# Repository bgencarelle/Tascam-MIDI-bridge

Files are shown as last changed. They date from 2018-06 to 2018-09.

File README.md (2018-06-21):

---
name: Midi to Tascam Serial Control
Usage: Midistudios and devices that use the Tascam Accessory 2 port.
---
**Goals:**

The goal of this project is to create an open device that can replace the obsolete and all but impossible-to-find sync devices for various Tascam tape machines.

**The desired functions:**

MIDI transport control of all functions available over the serial port.

SMPTE Time Code Chase to external reference.

Speed/pitch control of transport.

**Current Status:**

Midi control over all of the stuff controlled by the serial port for these devices has already been finished. You may want to change the CC's to something more useful by you, as they were setup to be most useful with my MIDI controller.

There are two sketches-one solely for external control and one for external control plus SMPTE sync.

The timing sync is not finished as of June 2018, but the decoders both work well.

I do plan on adding DAC based pitch control, whether or not I get the timing working.

I also plan on generalizing this to make for a control thing for non-serial enabled tape machines.

This is written for the Arduino UNO as it is cheap and easily sourced, but, virtually anything Arduino compatible will work.

Obviously USB midi and Bluetooth can be used, but are not currently implemented.

**Hardware roughly required**

Arduino compatible microcontroller.

Some sort of inverter/buffer to convert the UART data to reasonable voltages for RS-232.

Driver/inverter to get the LTC to digital levels.

Opto-isolator for standard MIDI.

**Hardware specifically used**

Arduino Uno with Midi Shield CD 4049 inverter for both converting LTC from audio to digital levels and two other pins for the UART inversion and voltage conversion.<p>
Various resistors and caps.
<p>USB FTDI UART thing for debugging.

You may want to use better hardware. I had no problems, but that doesn't mean anything!

**Notes on the Serial and MIDI format**

There is a pinout available in the documents as both a GIF and a PDF.

Basically just remember to connect your transmit to the device's receive.
Do not forget to both protect and invert the inputs to save your device from the higher and lower voltages that RS-232 uses.

The RS-232 format is 9600 baud, 8 bits, even parity, no handshaking.
This slightly odd format is why the standard SoftwareSerial library could not be used.

Each message is sent as a byte, or a pair of bytes followed by usual end of line characters.

Make sure to wait 100ms between messages. This won't be a problem usually.

**Attribution and licenses**

Use it, fork it, do whatever, but make sure to keep it freely available, give me a bit of credit and respect the licenses of the people who made these libraries.

https://creativecommons.org/licenses/by-sa/4.0/

The MIDI and LTC portions of this code are lifted from various Arduino.cc forums:
<http://arduino.cc>

SoftwareSerialParity comes from:
<https://github.com/ledongthuc/CustomSoftwareSerial>

This has been converted into an Arduino compatible library in the same directory as these sketches.

All related documents used for research can be found in this repository.

Thanks to Tascam for providing the documentation.

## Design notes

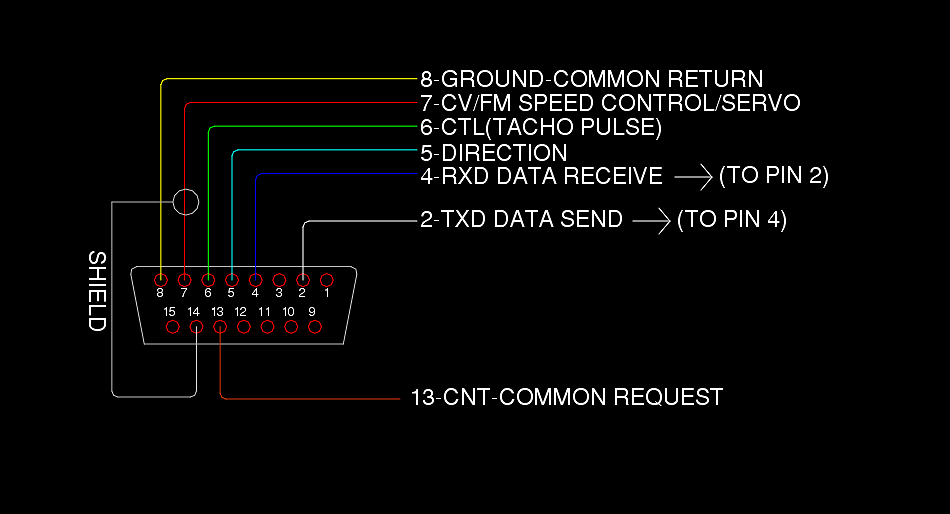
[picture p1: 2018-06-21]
diagrams/ACCESSORY2_pinout.gif

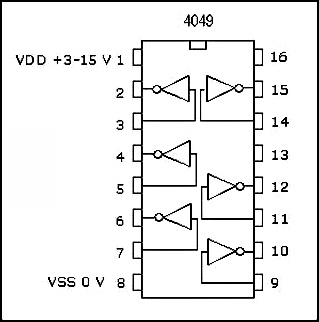
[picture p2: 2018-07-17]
diagrams/IC-CD4049.jpg

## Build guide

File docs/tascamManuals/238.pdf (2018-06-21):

Downloaded from www.Manualslib.com manuals search engine

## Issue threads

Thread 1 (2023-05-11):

Identifying the correct serial control codes for Tascam Tape Machines

aboutdereham, 2023-05-11:
Hello!
I have been considering undertaking a similar project to allow my DAW (Cakewalk) to send MIDI commands to remote control my Tascam 238 8-track machine via the ACCESSORY2 socket.  I already had a copy of the Tascam 'ACCESORY2' pdf which is useful but only provides remote control codes for Tascam CD machines.

Can I ask if you have been able to locate the correct serial controls codes for Tascam Tape Machines fitted with the Accessory2 socket?

By the way, Cakewalk is a good DAW to provide MIDI control commands to Tape Machines as there exists a utility called AZ Controller which allows the MIDI control signals from Cakewalk to be customised as either CCs or SysEx messages.  I have a working set up for Cakewalk to control most functions of my Fostex G24S 24-track machine.

jacksaturn, 2023-05-11:
I'm very interested in this – I'd be doing the same thing, except with Pro Tools and a pair of synced Tascam 238 machines.

If someone had access to a Tascam MTS-500, for example, should they hypothetically be able to monitor the MIDI/CC commands that it's outputting in order to figure this out?

bgencarelle, 2023-05-11:
Hi, thanks for checking out my abandonware project! I still mean to do
more, but have been working on a lot of other projects.

I was pretty bad about documenting all of this stuff, but I was able to get
full midi and serial sync control over multiple devices. The midi config
file has commands for controlling transport and the pinout is linked as
well. I even created a control map for the Beatstep pro.

https://github.com/bgencarelle/Tascam-MIDI-bridge/tree/nonblocking_chasesync/midi%20devices

https://github.com/bgencarelle/Tascam-MIDI-bridge/blob/nonblocking_chasesync/diagrams/ACCESSORY2_pinout.gif

https://github.com/bgencarelle/Tascam-MIDI-bridge/tree/nonblocking_chasesync/docs/tascamManuals

https://github.com/bgencarelle/Tascam-MIDI-bridge/blob/nonblocking_chasesync/src/TASCAM_MIDI_SMPTE_MAIN/MIDI_CONFIG.ino

https://github.com/bgencarelle/Tascam-MIDI-bridge/blob/nonblocking_chasesync/src/TASCAM_MIDI_SMPTE_MAIN/SMPTE_INCLUDES.ino

This has the midi commands that matter for controlling most acc 2 devices.

Kind Regards,

Ben Gencarelle

bgencarelle.com

instagram.com/bencarelle

On Thu, May 11, 2023 at 8:59 PM Jack Saturn ***@***.***>
wrote:

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

aboutdereham, 2023-05-12:
Hi Ben (and hi Jack)

Thanks for getting back!

I can see the serial character based commands in your 'MIDI_CONFIG.ino' programme, which is great.  May I ask some questions please:

1. I want to try to find a way to get the Tascam machine to move to a specified timecode position.  In my Fostex Tape machines (which have a MIDI based remote control protocol) there is a specific (SysEx) command to do this but it looks to be more difficult for Tascam machines.  I can see there is a Return to Zero Command "Z" but no way to say, 'GOTO hr, mn, sc, ff and then STOP'.  Have you any idea how I might implement this?

2. I plan to use a Tascam ATS-500 to do the actual syncing between Cakewalk DAW and the Tascam Tape Machine.  I have a utility on my DAW PC which converts MTC to LTC to feed the master LTC timecode to the ATS-500 and of course the slave LTC will come from Track 8 of the Tascam 238.  Finally my question:

Do you see any problem? if I make a special cable so that:

- The Serial RS232 pins 2 and 4 (of the Tascam ACCESSORY2) are fed from my PIC's serial port (via a TTL to RS232 convertor) for the remote control functions
- The sync pins are fed from the ATS-500, so that the Tascam Tape Machine is slave sync'd from the ATS-500

In order words, are the two functions (remote control and sync) entirely separate?

3. Have you be able to identify which pins on the ACCESSORY2 socket are used for the sync function? (so I can make the split cable correctly.

Regards
Robert

bgencarelle, 2023-05-12:
Hi Robert,

1: There may be a solution in my code, but it's been five years. I walked
away from this in the middle of merging branches, so there is a lot of
stuff scattered across everything, sorry. I remember chasing sync was a
problem, but I think what I did was calculate rate of fw/rewind time,
roughly transport to said time and check. If within a certain number of
frames, speedup/slowdown until first sync and then resume normal playback.
I think the way tascam handled it was to count the number of sync pulses
over the acc2 cable to estimate transport speed and then do the same thing.
I think I was working on setting that up when things went weird for a bit
and then 2020 happened and I got locked in the house with 3 young kids.

2. I was using ltc and mtc with reaper for the same scenario. I'd have
reaper be both the slave and master for testing. I got really solid
results, like close to subframe accuracy for syncing, pretty close to what
tape can offer.

The sync function stuff is all laid out here: From what I can remember, 7
was the thing that controlled speed of motor, 6 is our clock that varies
with transport speed, 5 tells us direction of transport.

https://github.com/bgencarelle/Tascam-MIDI-bridge/blob/nonblocking_chasesync/diagrams/ACCESSORY2_pinout.gif

Kind Regards,

Ben Gencarelle

bgencarelle.com

instagram.com/bencarelle

On Fri, May 12, 2023 at 11:07 AM aboutdereham ***@***.***>
wrote:

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

bgencarelle, 2023-05-12:
sorry, I missed the other question-yes, remote control and sync are
unrelated. If you look into my midi includes, I have all of the commands
you can use listed. It would be pretty easy to make a software midi
controller for these things with this info.

Kind Regards,

Ben Gencarelle

bgencarelle.com

instagram.com/bencarelle

On Fri, May 12, 2023 at 11:07 AM aboutdereham ***@***.***>
wrote:

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

aboutdereham, 2023-05-12:
Hi Ben
Thanks for your replies which all make sense!
I need to find an ATS-500 which are now pretty rare but once I get one I'll get the sync from Cakewalk to Tascam 238 working and then tackle the basic remote control stuff.  Then I'll have a look at the locate to timecode position.  I think your proposed method should work okay.  The PIC I use is fast enough to do the sync pulse counting and issue the appropriate commands to the Tascam machine.
I'll let you now how it goes.
Regards
Robert

bgencarelle, 2023-05-12:
I can tell you that the arduino midi stuff works great for midi remote
control and it's what I used- you would just map the serial commands to
midi like I did to fill in the midi control gap.

The ultimate goal of this project was to use off the shelf hardware to
replace the hard to find midi sync stuff. Everything but the ATMega
specific timing for the smpte/LTC/MTC stuff would probably work fine with
whatever microcontroller you use if you can use it with Arduino.

That said, if you're in the EU, I've got one I used for testing purposes,
as well as some Tascam 644s and a broken 238s. My wife has been bugging me
to either set them up or make some space in our basement.

Kind Regards,

Ben Gencarelle

bgencarelle.com

instagram.com/bencarelle

On Fri, May 12, 2023 at 12:13 PM aboutdereham ***@***.***>
wrote:

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

aboutdereham, 2023-05-12:
Hi Ben
I'm in the UK but we have relatives in Germany and Holland.
If you are interested in parting with the 238S (I'm assuming its the Dolby S?) then I would be happy to take it on as a repair project.  The Dolby subcards are a serious project to fix but it would be fun.  Let me know!
Regards
Robert

bgencarelle, 2023-05-12:
sounds good! I've got a midiizer too, should have mentioned that.
my email:

***@***.***

Kind Regards,

Ben Gencarelle

bgencarelle.com

instagram.com/bencarelle

On Fri, May 12, 2023 at 1:42 PM aboutdereham ***@***.***>
wrote:

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

jacksaturn, 2024-09-26:
Revisiting this conversation. @aboutdereham , you mentioned that you were trying to sync Cakewalk with a Tascam 238. Did you ever have any success?

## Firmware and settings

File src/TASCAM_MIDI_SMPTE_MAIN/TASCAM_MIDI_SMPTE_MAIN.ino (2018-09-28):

/*   Tascam Serial Control for Midistudios and devices that use the Accessory 2 port.

//ff time 1:23 
//rw time 1:16 
//pin 13 on the controller handles chaseMode 
//pin 5 is direction-rw is low ff/play/stop is high 
//pin 6 is tach pulse  3.22 hz is play, rw is between 25 and ~78hz ends low, ff is 44 to 30 hz,play is 2.92hz 

   The goal of this project is to create an open device that can replace the obsolete and
   all but impossible-to-find sync devices for various Tascam tape machines.
  See the Readme.md for more details
   2018 Ben Gencarelle
*/
#include <MIDI.h>
#include <Tone.h>
#include <Wire.h>
#include "SSD1306Ascii.h"
#include "SSD1306AsciiWire.h"
SSD1306AsciiWire oled;

volatile bool writeLTCOut;
volatile bool writeMTCOut;
Tone playSpeed; 

#define TIME_SYNC 1 //comment this out for just MIDI control over serial port
//#define EXTERNAL_CONTROL 1 // to use for generalized control
#define MIDI_CONTROL 1
#define OLED_MODE 1
#if !defined(TIME_SYNC) 
  #define STRIPE_MODE 1 
#endif 

#if defined(__AVR_ATmega328__) || defined(__AVR_ATmega328P__) || defined(__AVR_ATmega168__) 
//UNO like
#define UNO 1 //for interrupt stuff
#define icpPin 8 // ICP input pin on arduino
#define MOTOR_SPEED_LOW 6400 
#define MOTOR_SPEED_RUN 9600 
#define MOTOR_SPEED_HIGH 12800
#include <SoftwareSerialParity.h>// Not needed for devices with multiple UARTS
SoftwareSerialParity SerialOne(6, 7); // RX, TX
MIDI_CREATE_DEFAULT_INSTANCE();

#elif (__AVR_ATmega2560__) || defined(__AVR_ATmega1280__) || defined(__AVR_ATmega640__) || defined(__AVR_ATmega328PB__)
#define MEGA 1 //for interrupt stuff
#define icpPin  48// ICP input pin on arduino -not needed as handled by interrupt
#define EVEN SERIAL_8E1
HardwareSerial & SerialOne = Serial1;
MIDI_CREATE_DEFAULT_INSTANCE();
#define MOTOR_SPEED_LOW 6400 
#define MOTOR_SPEED_RUN 9600 
#define MOTOR_SPEED_HIGH 12800 
#endif

int chaseStateControlPin= 9; 
int chaseFrequencyPin=11;  

void setup()
{

  SerialOne.begin(9600, EVEN);
  SerialOne.println('S');
  pinMode(chaseFrequencyPin,OUTPUT); 
  pinMode(chaseStateControlPin,OUTPUT); 
  digitalWrite(chaseStateControlPin, LOW); 
  delay(100); 
  digitalWrite(chaseStateControlPin, HIGH); 
  playSpeed.begin(chaseFrequencyPin);// 
  playSpeed.play(MOTOR_SPEED_RUN);// 
  
#if defined (STRIPE_MODE) 
  stripeSetup();//  
#endif 
#if defined (MIDI_CONTROL)
  midiSetup();
#endif

#if defined (OLED_MODE)
oledSetup(); 
#endif

#if defined (TIME_SYNC)
 smpteSetup();
#endif

}

void loop()
{
#if defined (MIDI_CONTROL) && !defined (STRIPE_MODE) 
  MIDI.read();
#endif

}

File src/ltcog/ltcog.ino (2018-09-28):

#define icpPin 8        // ICP input pin on arduino
#define ONE_TIME_MAX          475 // THESE VALUES ARE SETUP FOR NTSC VIDEO
#define ONE_TIME_MIN          150 // PAL WOULD BE AROUND 1000 FOR 0 AND 500 FOR 1
#define ZERO_TIME_MAX         1900 // 80BITS TIMES 29.97 FRAMES PER SEC
#define ZERO_TIME_MIN         600 // EQUALS 833 (DIVIDE BY 8 CLOCK PULSES)

#define END_DATA_POSITION      63
#define END_SYNC_POSITION      77
#define END_SMPTE_POSITION     80

volatile unsigned int bitTime;
volatile boolean validTcWord;
volatile boolean onesBitCount;
volatile boolean tcSync;
volatile boolean writeTcOut;
volatile boolean dropFrameFlag;

volatile byte hoursLTC, minutesLTC, secondsLTC, framesLTC;      //hours, minutes, seconds, frame
volatile unsigned int MTCWord = 0;
String LTCWord= "This is a really long string";

volatile byte totalBits;
volatile bool currentBit;
volatile byte syncCount;

volatile unsigned int tc[10];
volatile unsigned int bufferLTC[10];
volatile char timeCodeLTC[13];

/* ICR interrupt vector */
ISR(TIMER4_CAPT_vect)
{
 //toggleCaptureEdge
 TCCR4B ^= _BV(ICES4);

 bitTime = ICR4;

 //resetTimer1
 TCNT4 = 0;

 if ((bitTime < ONE_TIME_MIN) || (bitTime > ZERO_TIME_MAX)) // get rid of anything way outside the norm
 {
   //Serial.println(bitTime, DEC);
   totalBits = 0;
 }
 else
 {
   if (onesBitCount == true) // only count the second ones pluse
  {
     onesBitCount = false;
  }
   else
   {
     if (bitTime > ZERO_TIME_MIN)
     {
       currentBit = 0;
       syncCount = 0;
     }
     else //if (bitTime < oneTimeMax)
     {
       onesBitCount = true;
       currentBit = 1;

     }

    for (int i = 0; i < 9; i ++) {
       tc[i] = (tc[i] >> 1) | ((tc[i + 1] & 1) ? 0x80 : 0);
       bufferLTC[i] = tc[i];
    }
   tc[9] = (tc[9] >> 1) | (currentBit ? 0x80 : 0);
     totalBits++;
   }

    if (tc[8] == 0xfc && tc[9] == 0xbf && totalBits >= 80)
    {
        validTcWord=true;
        totalBits = 0;
    }

   if (validTcWord)
   {
     validTcWord = false;
      framesLTC = (((bufferLTC[1] & 0x07) * 10) + (bufferLTC[0] & 0x0F));
      secondsLTC = (((bufferLTC[3] & 0x07) * 10) + (bufferLTC[2] & 0x0F));
      minutesLTC = (((bufferLTC[5] & 0x07) * 10) + (bufferLTC[4] & 0x0F));
      hoursLTC = (((bufferLTC[7] & 0x07) * 10) + (bufferLTC[6] & 0x0F));
      LTCWord = String((hoursLTC)) + ":" + String((minutesLTC)) + ":" + String(secondsLTC)+":" +String (framesLTC);

     dropFrameFlag = bit_is_set(tc[1], 2);

     writeTcOut = true;
   }
 }
}


void setup()
{

 Serial.begin (9600);
 pinMode(icpPin, INPUT);                  // ICP pin (digital pin 8 on arduino) as input

 bitTime = 0;
 validTcWord = false;
 onesBitCount = false;
 tcSync = false;
 writeTcOut = false;
 dropFrameFlag = false;
 totalBits =  0;
 currentBit =  0;
 syncCount =  0;

 //Serial.println("Finished setup ");
 //delay (1000);

 TCCR4A = B00000000; // clear all
 TCCR4B = B11000010; // ICNC1 noise reduction + ICES1 start on rising edge + CS11 divide by 8
 TCCR4C = B00000000; // clear all
 TIMSK4 = B00100000; // ICIE1 enable the icp

 TCNT4 = 0; // clear timer1
}

void loop()
{
   if (writeTcOut)
   {
     writeTcOut = false;
     if (dropFrameFlag)
       Serial.print("TC-[df] ");
     else
       Serial.print("TC-[nd] ");
     Serial.print(LTCWord);
     Serial.println("\r");
   }
}

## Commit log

2018-06-21 fixed minor issues
    Split LTC MTC and basic midi into different files.
    Will adopt same approach for
    [SMPTE_INCLUDES.ino]
2018-06-22 Added a fritzing thing to make it less clear
    [arduino_tascam_serial_midi.fzz]
2018-06-22 Added some folders
    [arduino_tascam_serial_midi.fzz]
2018-07-13 added some error checking,
    tested on Uno
    [MIDI_CONFIG.ino, SMPTE_INCLUDES.ino, TASCAM_MIDI_SMPTE_MAIN.ino]
2018-07-14 Still having end of tape problems, but getting closer
    Woot
    [MIDI_CONFIG.ino, SMPTE_INCLUDES.ino, TASCAM_MIDI_SMPTE_MAIN.ino]
2018-07-17 not working fully
    Getting weird issues
    [SMPTE_INCLUDES.ino, STRIPE_MODE.ino, TASCAM_MIDI_SMPTE_MAIN.ino]
2018-07-17 Sub frame accuracy!
    Still have ff/rw issues
    [SMPTE_INCLUDES.ino, TASCAM_MIDI_SMPTE_MAIN.ino]
2018-07-29 adding better error cottection
    [OLED_MODE.ino, SMPTE_INCLUDES.ino, TASCAM_MIDI_SMPTE_MAIN.ino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]
2018-09-28 Created 328PB tone library
    woot! 16 bit timer goodness
